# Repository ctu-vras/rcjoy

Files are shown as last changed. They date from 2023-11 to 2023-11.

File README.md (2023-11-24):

# rcjoy
Boost gamepad control of ROS robots to kilometer ranges and 100% reliability. Throw away all your nano dongles :)

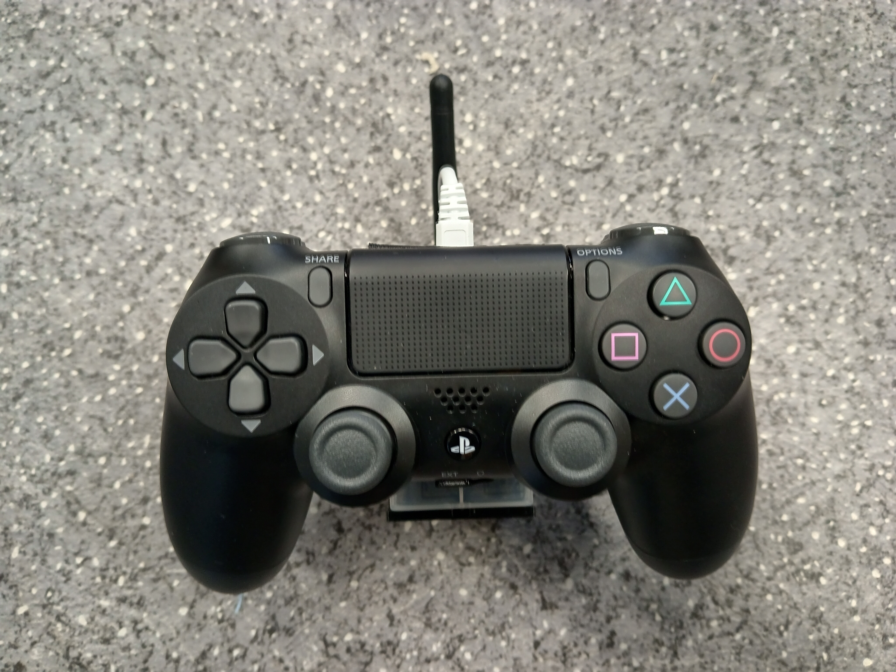
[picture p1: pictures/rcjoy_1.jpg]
rcjoy

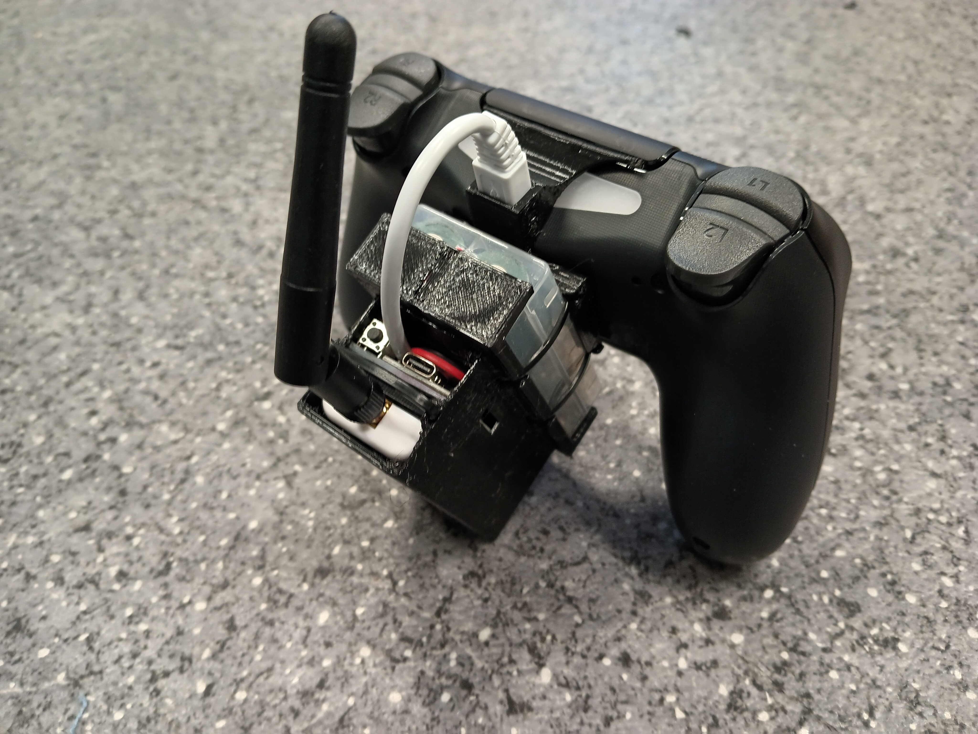
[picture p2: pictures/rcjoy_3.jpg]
rcjoy

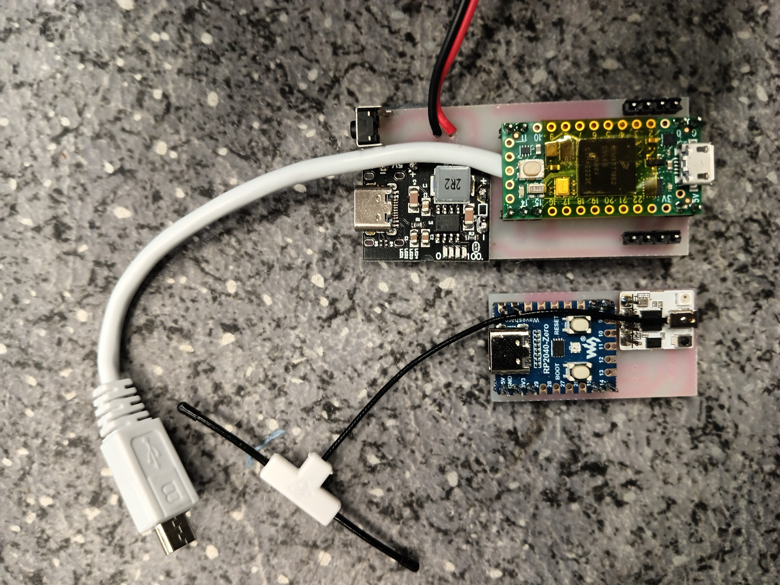
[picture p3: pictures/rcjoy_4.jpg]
rcjoy


# How it works
The rcjoy is intended to be a drop in replacement of a wireless gamepad like xbox controller or Logitech F710.  
The transmitter mcu (Teensy 4.0) acts as an usb host reading data from PS4 controller connected by wire, converts them to packets and send them via SBUS to tx module (ImmersionRC Ghost lite).  
The receiverer mcu (RP2040) acts as usb hid joystick emulator, reads SBUS packets decodes them and mimic gamepad controller connected to robot's PC.  
At this moment is communication one directional.

# BoM
  * PS4 Dualshock 4 controller  
   https://www.playstation.com/cs-cz/accessories/dualshock-4-wireless-controller/
  * ImmersionRC Ghost xLite Module  
   https://shop.orqafpv.com/products/immersionrc-immersionrc-ghost-xlite-module
  * ImmersionRC Ghost Atto Receiver  
   https://shop.orqafpv.com/products/immersionrc-immersionrc-ghost-atto-receiver
  * Teensy® 4.0 Development Board  
   https://www.pjrc.com/store/teensy40.html
  * Waveshare RP2040-Zero  
   https://www.waveshare.com/rp2040-zero.htm
  * Powerbank module  
   https://www.laskakit.cz/nabijecka-boost-pro-usb-powerbank-5v--usb-c/
  * Two LiIon 18650 cells

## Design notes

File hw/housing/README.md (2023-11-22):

# 3D printable mounting
The mounting hardware consists of universal DualShock 4 mount and main box with batteries. They attach togather with zip-ties running around the battery.
The 3D printing guide is available at https://www.printables.com/cs/model/655724-dualshock-4-range-extender-with-mount
The box is designed that it can be used as a stand for the controller itself. 

Reciever box is also provided which provides mounting for the antenna and the reciver itself. 

The wall mount is not required but provides a way of easily mounting the holder to a wall.

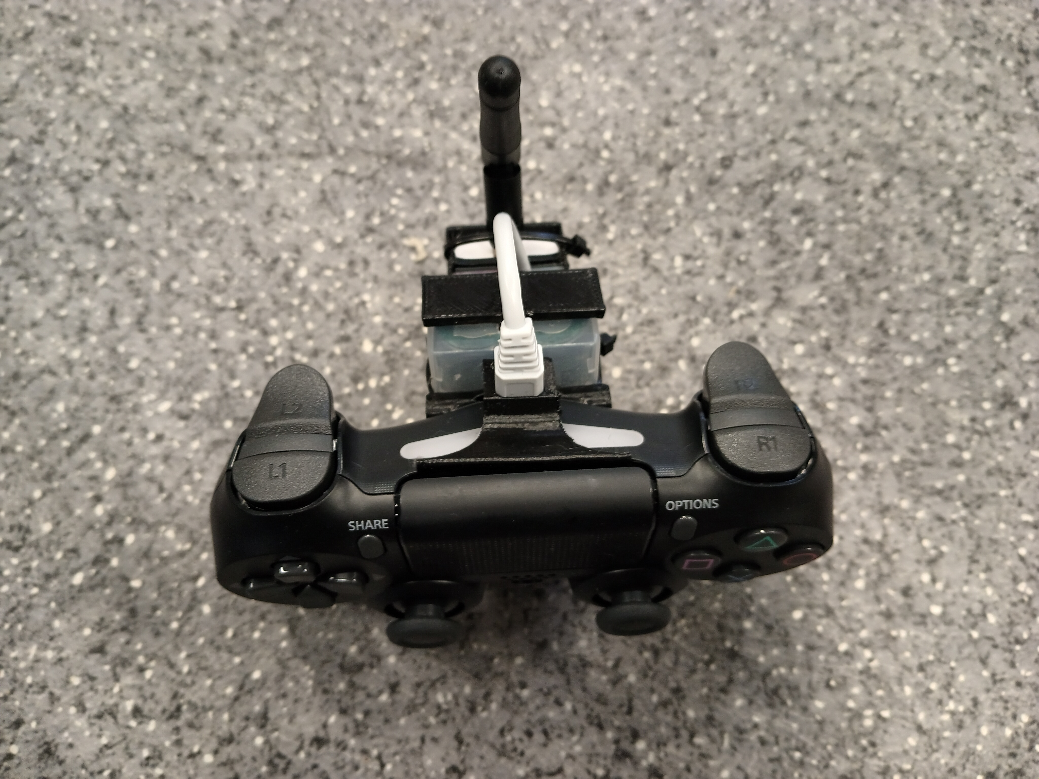
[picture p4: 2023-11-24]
pictures/rcjoy_2.jpg

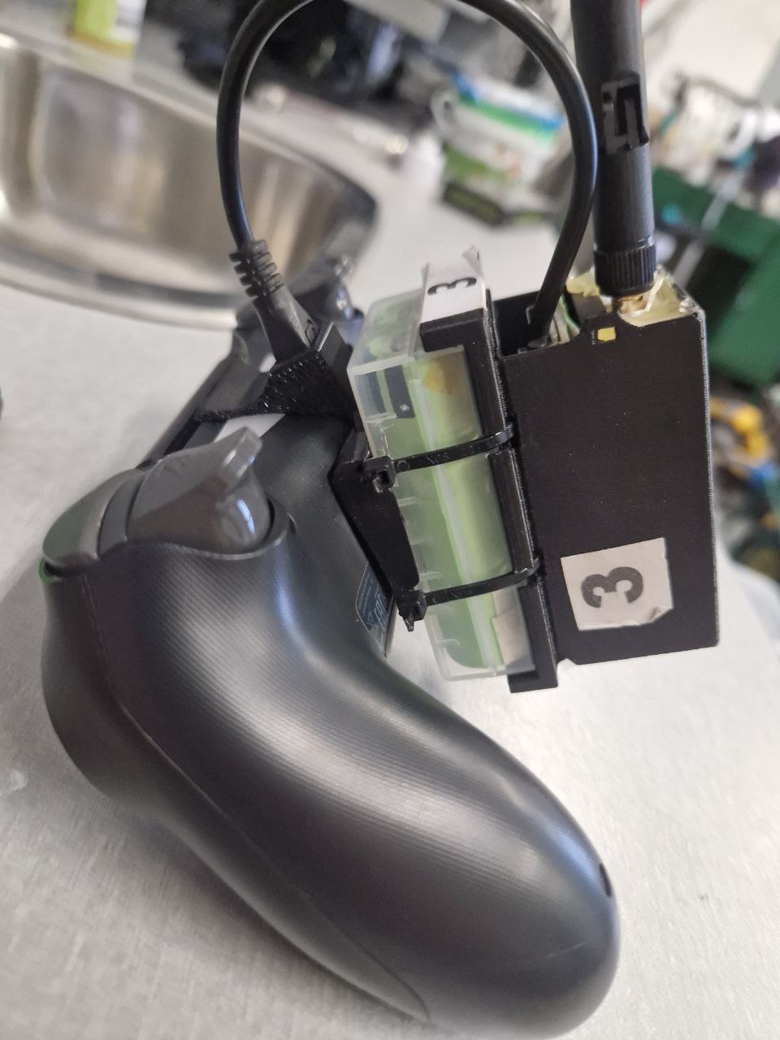
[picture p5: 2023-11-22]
hw/housing/final_assmbly.jpg

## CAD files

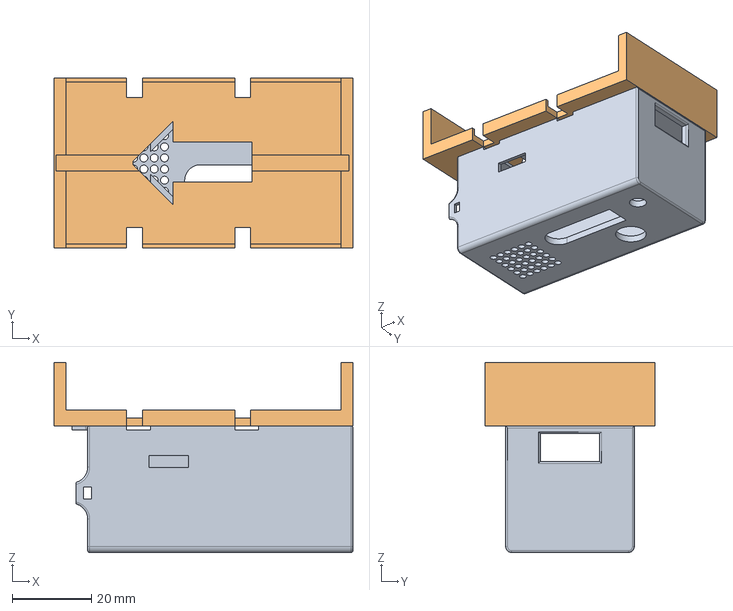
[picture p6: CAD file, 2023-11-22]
hw/housing/main_box_with_batteries.step
75.5 x 43.0 x 48.0 mm

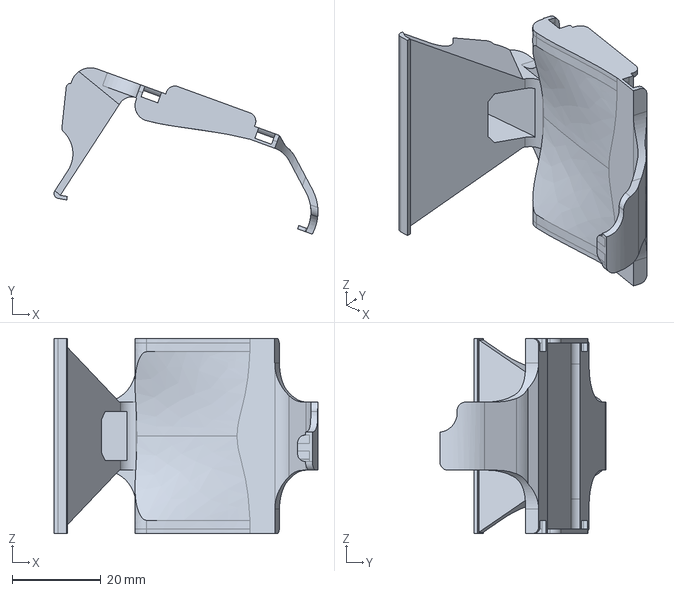
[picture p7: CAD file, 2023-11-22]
hw/housing/dualshock_4_mount.step
59.5 x 37.5 x 44.0 mm

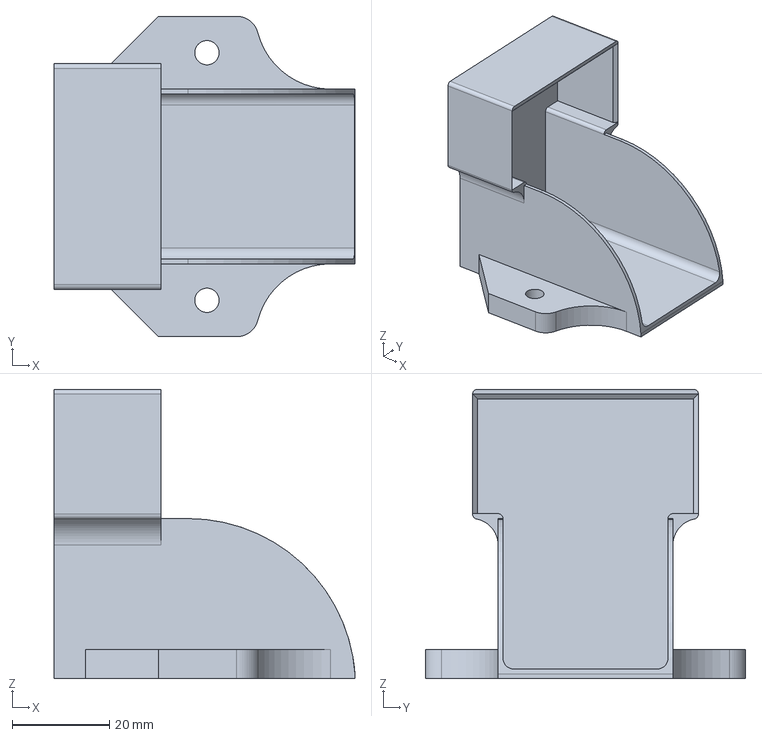
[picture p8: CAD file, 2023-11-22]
hw/housing/wall_mount.step
62.0 x 66.0 x 59.6 mm

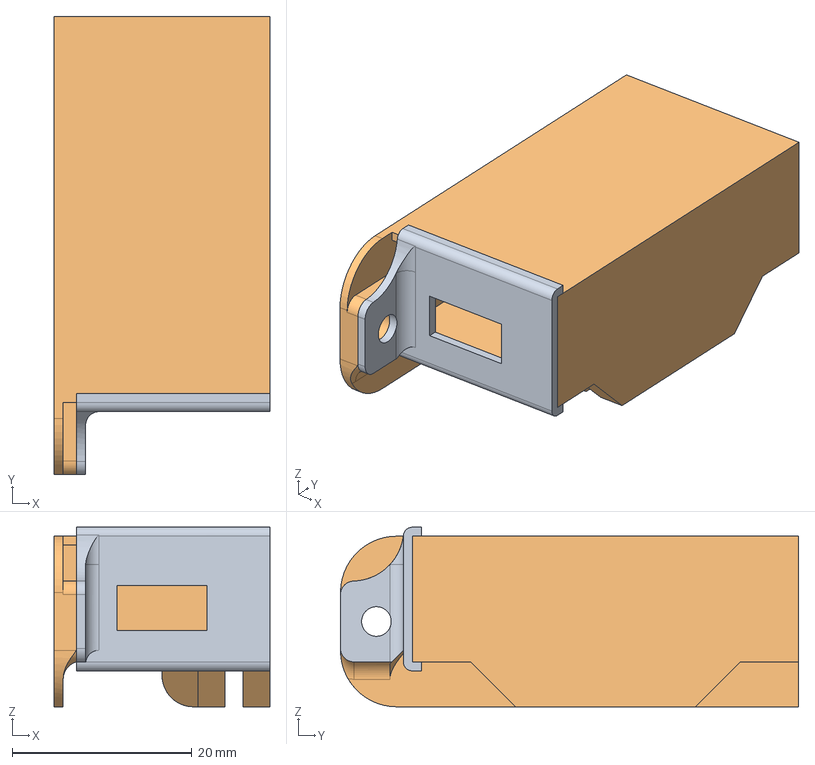
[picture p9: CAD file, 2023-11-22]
hw/housing/reciever_box.step
24.0 x 51.0 x 20.0 mm

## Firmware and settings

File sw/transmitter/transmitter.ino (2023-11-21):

//Teensy 4.0 code
//https://www.pjrc.com/store/teensy40.html


/*
  Exclusions for channels 0-3
  15
  271
  527
  783
  1039
  1295
  1551
  1807
  Channels 4-11 are just 8bit values, multiplication to full scale should work
  For simplicity all channels are considered as 8bit   
*/



#include "USBHost_t36.h"
//https://github.com/PaulStoffregen/USBHost_t36
//part of TeensyDuino 1.58
#include "sbus.h"
//https://github.com/bolderflight/sbus 
//v 8.1.4

uint8_t databyte[12];  //12 8-bit channels
bfs::SbusTx sbus_tx(&Serial3);
/* Array for storing SBUS data */
//std::array<int16_t, bfs::SbusRx::NUM_CH()> sbus_data;
bfs::SbusData sbus_data;


USBHost myusb;
USBHub hub1(myusb);
USBHIDParser hid1(myusb);

#define COUNT_JOYSTICKS 4
JoystickController joysticks[COUNT_JOYSTICKS] = {
  JoystickController(myusb), JoystickController(myusb),
  JoystickController(myusb), JoystickController(myusb)
};
int user_axis[64];
uint32_t buttons_prev = 0;

USBDriver *drivers[] = { &hub1, &joysticks[0], &joysticks[1], &joysticks[2], &joysticks[3], &hid1 };
#define CNT_DEVICES (sizeof(drivers) / sizeof(drivers[0]))
const char *driver_names[CNT_DEVICES] = { "Hub1", "joystick[0D]", "joystick[1D]", "joystick[2D]", "joystick[3D]", "HID1" };
bool driver_active[CNT_DEVICES] = { false, false, false, false };

// Lets also look at HID Input devices
USBHIDInput *hiddrivers[] = { &joysticks[0], &joysticks[1], &joysticks[2], &joysticks[3] };
#define CNT_HIDDEVICES (sizeof(hiddrivers) / sizeof(hiddrivers[0]))
const char *hid_driver_names[CNT_DEVICES] = { "joystick[0H]", "joystick[1H]", "joystick[2H]", "joystick[3H]" };
bool hid_driver_active[CNT_DEVICES] = { false };
bool show_changed_only = false;

uint8_t joystick_left_trigger_value[COUNT_JOYSTICKS] = { 0 };
uint8_t joystick_right_trigger_value[COUNT_JOYSTICKS] = { 0 };
uint64_t joystick_full_notify_mask = (uint64_t)-1;

int psAxis[64];
//int minaxis, maxaxis, mintrig, maxtrig;

uint8_t button[6];
uint16_t buttmp;



//=============================================================================
// Setup
//=============================================================================
void setup() {
  /* Begin the SBUS communication */
  databyte[0] = 127;
  databyte[1] = 127;
  databyte[2] = 0;
  databyte[3] = 127;
  databyte[4] = 127;
  databyte[5] = 0;
  databyte[6] = 0;
  databyte[7] = 0;
  databyte[8] = 4; //sbus data are generated by transmitter program
  databyte[9] = 0;
  databyte[10] = 0;
  databyte[11] = 0;
  for (uint8_t i = 0; i < 12; i++) {
    sbus_data.ch[i] = databyte[i] * 8;
  }
  
  sbus_tx.Begin();
  sbus_tx.data(sbus_data);
  sbus_tx.Write();

  Serial.begin(115200);

  Serial.println("PS4 GHOST RCJOY STARTING");
  myusb.begin();
}


//=============================================================================
// loop
//=============================================================================
void loop() {
  myusb.Task();



  //  for (int joystick_index = 0; joystick_index < COUNT_JOYSTICKS; joystick_index++)
  //    joysticks[joystick_index].axisChangeNotifyMask(joystick_full_notify_mask);

  for (int joystick_index = 0; joystick_index < COUNT_JOYSTICKS; joystick_index++)
    joysticks[joystick_index].axisChangeNotifyMask(0xffffffffffffffff);

  for (int joystick_index = 0; joystick_index < COUNT_JOYSTICKS; joystick_index++) {
    if (joysticks[joystick_index].available()) {
      //uint64_t axis_mask = joysticks[joystick_index].axisMask();
      //uint64_t axis_changed_mask = joysticks[joystick_index].axisChangedMask();
      uint32_t buttons = joysticks[joystick_index].getButtons();
      //Serial.printf("Joystick(%d): buttons = %x", joystick_index, buttons);
      //for (uint8_t i = 0; axis_mask != 0; i++, axis_mask >>= 1) {
      //  if (axis_mask & 1) {
      //    Serial.printf(" %d:%d", i, joysticks[joystick_index].getAxis(i));
      //    Serial.println();
      //  }
      //}
      switch (joysticks[joystick_index].joystickType()) {
        default:
          break;
        case JoystickController::PS4:
          {
            databyte[0] = joysticks[joystick_index].getAxis(0);
            databyte[1] = joysticks[joystick_index].getAxis(1);
            databyte[2] = joysticks[joystick_index].getAxis(3);
            databyte[3] = joysticks[joystick_index].getAxis(2);
            databyte[4] = joysticks[joystick_index].getAxis(5);
            databyte[5] = joysticks[joystick_index].getAxis(4);

            databyte[6] = 1 * (buttons & 0x0002) / 0x0002 +   //A CROSS
                          2 * (buttons & 0x0004) / 0x0004 +   //B CIRCLE
                          4 * (buttons & 0x0001) / 0x0001 +   //X SQUARE
                          8 * (buttons & 0x0008) / 0x0008 +   //Y TRIANGLE
                          16 * (buttons & 0x0010) / 0x0010 +  //LTRIG
                          32 * (buttons & 0x0020) / 0x0020 +  //RTRIG
                          64 * (buttons & 0x0100) / 0x0100 +  //SHARE
                          128 * (buttons & 0x0200) / 0x0200;  //RHAT
                                                              //64 * (buttons & 0x0400) / 0x0400 + //LHAT
                                                              //128 * (buttons & 0x0800) / 0x0800; //RHAT
            //databyte[7] = 0;
            databyte[7] = 0 + 1 * (buttons & 0x1000) / 0x1000 +  //PS
                          2 * (buttons & 0x0400) / 0x0400 +      //LHAT
                          4 * (buttons & 0x0800) / 0x0800 +      //RHAT
                          8 * (buttons & 0x2000) / 0x2000;       //TOUCH

            //databyte[8] = ((joysticks[joystick_index].getAxis(9) & 0b00000111) + 1);
            uint8_t hat = joysticks[joystick_index].getAxis(9);
            //(hat == 8) ? databyte[8] = 0 : (databyte[8] = hat + 1) * 16;
            if (hat != 8) databyte[7] += (hat + 1) * 16;
            /*databyte[8] = 0;
            switch (joysticks[joystick_index].getAxis(9)) {
              case 0: databyte[8] += 1; break;
              case 1: databyte[8] += 2; break;
              case 2: databyte[8] += 3; break;
              case 3: databyte[8] += 4; break;
              case 4: databyte[8] += 5; break;
              case 5: databyte[8] += 6; break;
              case 6: databyte[8] += 7; break;
              case 7: databyte[8] += 8; break;
              case 8: databyte[8] += 0; break;
              default: break;
            }
            */
            //databyte[8]=4;


            for (uint8_t n = 0; n < 12; n++) {
              Serial.println(databyte[n]);
            }
            Serial.println();
            //Serial.println(millis());
          }
          for (uint8_t i = 0; i < 12; i++) {
            sbus_data.ch[i] = databyte[i] * 8;
          }
          sbus_data.ch[8]=32; //sbus data are generated by transmitter program
          sbus_tx.data(sbus_data);
          sbus_tx.Write();

          Serial.println();
          joysticks[joystick_index].joystickDataClear();
      }
    }
  }
  PrintDeviceListChanges();
  delay(20);
}

//=============================================================================
// Show when devices are added or removed
//=============================================================================
void PrintDeviceListChanges() {
  for (uint8_t i = 0; i < CNT_DEVICES; i++) {
    if (*drivers[i] != driver_active[i]) {
      databyte[0] = 127;
      databyte[1] = 127;
      databyte[2] = 0;
      databyte[3] = 127;
      databyte[4] = 127;
      databyte[5] = 0;
      databyte[6] = 0;
      databyte[7] = 0;
      databyte[8] = 4; //sbus data are generated by transmitter program
      databyte[9] = 0;
      databyte[10] = 0;
      databyte[11] = 0;
      for (uint8_t i = 0; i < 12; i++) {
        sbus_data.ch[i] = databyte[i] * 8;
      }
      sbus_tx.data(sbus_data);
      sbus_tx.Write();

      if (driver_active[i]) {
        Serial.printf("*** Device %s - disconnected ***\n", driver_names[i]);
        driver_active[i] = false;

      } else {
        Serial.printf("*** Device %s %x:%x - connected ***\n", driver_names[i], drivers[i]->idVendor(), drivers[i]->idProduct());
        driver_active[i] = true;

        const uint8_t *psz = drivers[i]->manufacturer();
        if (psz && *psz) Serial.printf("  manufacturer: %s\n", psz);
        psz = drivers[i]->product();
        if (psz && *psz) Serial.printf("  product: %s\n", psz);
        psz = drivers[i]->serialNumber();
        if (psz && *psz) Serial.printf("  Serial: %s\n", psz);
      }
    }
  }

  for (uint8_t i = 0; i < CNT_HIDDEVICES; i++) {
    if (*hiddrivers[i] != hid_driver_active[i]) {
      databyte[0] = 127;
      databyte[1] = 127;
      databyte[2] = 0;
      databyte[3] = 127;
      databyte[4] = 127;
      databyte[5] = 0;
      databyte[6] = 0;
      databyte[7] = 0;
      databyte[8] = 4; //sbus data are generated by transmitter program
      databyte[9] = 0;
      databyte[10] = 0;
      databyte[11] = 0;
      for (uint8_t i = 0; i < 12; i++) {
        sbus_data.ch[i] = databyte[i] * 8;
      }
      sbus_tx.data(sbus_data);
      sbus_tx.Write();

      if (hid_driver_active[i]) {
        Serial.printf("*** HID Device %s - disconnected ***\n", hid_driver_names[i]);
        hid_driver_active[i] = false;

      } else {
        Serial.printf("*** HID Device %s %x:%x - connected ***\n", hid_driver_names[i], hiddrivers[i]->idVendor(), hiddrivers[i]->idProduct());
        hid_driver_active[i] = true;

        const uint8_t *psz = hiddrivers[i]->manufacturer();
        if (psz && *psz) Serial.printf("  manufacturer: %s\n", psz);
        psz = hiddrivers[i]->product();
        if (psz && *psz) Serial.printf("  product: %s\n", psz);
        psz = hiddrivers[i]->serialNumber();
        if (psz && *psz) Serial.printf("  Serial: %s\n", psz);
      }
    }
  }
}

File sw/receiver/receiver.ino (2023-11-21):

//RPi pico code 
//Waveshare RP2040 zero
//https://www.waveshare.com/wiki/RP2040-Zero

#include <Adafruit_TinyUSB.h>
//Change USB Stack to "Adafruit TinyUSB"

#include "sbus.h"
//https://github.com/bolderflight/sbus 
//v 8.1.4
#include <Adafruit_NeoPixel.h>
//https://github.com/adafruit/Adafruit_NeoPixel
//V1.12.0

extern "C" {
#include <hardware/watchdog.h>
};
//https://raspberrypi.github.io/pico-sdk-doxygen/group__hardware__watchdog.html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

// HID report descriptor using TinyUSB's template
// Single Report (no ID) descriptor
uint8_t const desc_hid_report[] = {
  TUD_HID_REPORT_DESC_GAMEPAD()
};

// USB HID object. For ESP32 these values cannot be changed after this declaration
// desc report, desc len, protocol, interval, use out endpoint
Adafruit_USBD_HID usb_hid(desc_hid_report, sizeof(desc_hid_report), HID_ITF_PROTOCOL_NONE, 2, false);

// Report payload defined in src/class/hid/hid.h
// - For Gamepad Button Bit Mask see  hid_gamepad_button_bm_t
// - For Gamepad Hat    Bit Mask see  hid_gamepad_hat_t
hid_gamepad_report_t gp;






/* SbusRx object on Serial1 */
bfs::SbusRx sbus_rx(&Serial1);
//std::array<int16_t, bfs::SbusRx::NUM_CH()> sbus_data;
bfs::SbusData sbus_data;

uint16_t buttmp1, buttmp2;
uint32_t buttmp;
uint8_t button1[8], button2[8];

Adafruit_NeoPixel pixels(1, 16, NEO_RGB + NEO_KHZ800);
uint8_t r, g, b;

uint64_t lastRXtime;
uint32_t timeout = 1000;
uint32_t timeout_count = 10;

void setup() {
  TinyUSBDevice.setSerialDescriptor("rcjoy");
  Serial.begin(115200);
  // Serial to display the received data

#if defined(ARDUINO_ARCH_MBED) && defined(ARDUINO_ARCH_RP2040)
  // Manual begin() is required on core without built-in support for TinyUSB such as mbed rp2040
  TinyUSB_Device_Init(0);
#endif


  usb_hid.begin();

  // wait until device mounted
  while (!TinyUSBDevice.mounted()) delay(1);

  gp.x = 0;
  gp.y = 0;
  gp.z = -127;
  gp.rx = 0;
  gp.ry = 0;
  gp.rz = -127;
  gp.hat = 0;
  gp.buttons = 0;  //Maybe DMS should be forced to push???
  usb_hid.sendReport(0, &gp, sizeof(gp));

  //Serial.begin(115200);
  //while (!Serial) {}

  /* Begin the SBUS communication */
  sbus_rx.Begin();


  Serial.println("rcjoy Init");
  //pinMode(25, OUTPUT);

  pixels.begin();
  pixels.clear();
  pixels.setPixelColor(0, pixels.Color(0, 0, 0));
  pixels.show();
  watchdog_enable(100000, 1);
}

void loop() {

  if (lastRXtime + timeout < millis()) {
    Serial.println("Timeout!");
    r = 255;
    g = 0;
    gp.x = 0;
    gp.y = 0;
    gp.z = -127;
    gp.rx = 0;
    gp.ry = 0;
    gp.rz = -127;
    gp.hat = 0;
    gp.buttons = 0;  //Maybe DMS should be forced to push???
    usb_hid.sendReport(0, &gp, sizeof(gp));
    delay(100);
  } else {
    watchdog_update();
    r = 0;
    g = 255;
  }

  if (!usb_hid.ready()) {
    //return;
    b = 255;
  } else {
    b = 0;
  }
  pixels.setPixelColor(0, pixels.Color(r, g, b));
  pixels.show();

  //if ((sbus_rx.Read()) && (sbus_data.ch[8]==32)) {
  if (sbus_rx.Read()) {
    lastRXtime = millis();
    sbus_data = sbus_rx.data();
    /* Display the received data */

    for (int i = 0; i < 9; i++) {
      Serial.print(sbus_data.ch[i] / 8);
      Serial.print(",");
    }
    Serial.println();

    buttmp1 = sbus_data.ch[6] / 8;
    for (uint8_t b = 0; b < 8; b++) {
      button1[b] = buttmp1 % 2;
      buttmp1 /= 2;
      Serial.print(button1[b]);
      Serial.print("\t");
    }

    buttmp2 = ((sbus_data.ch[7] / 8) & 0b1111);
    for (uint8_t b = 0; b < 8; b++) {
      button2[b] = buttmp2 % 2;
      buttmp2 /= 2;
      Serial.print(button2[b]);
      Serial.print("\t");
    }

    Serial.println("");
    //Serial.println("");


    buttmp = 1 * button1[0] + 2 * button1[1] + 4 * button1[2] + 8 * button1[3] + 16 * button1[4] + 32 * button1[5] + 64 * button1[6] + 128 * button1[7] + 256 * button2[0] + 512 * button2[1] + 1024 * button2[2] + 2048 * button2[3] + 4096 * button2[4] + 8192 * button2[5] + 16384 * button2[6] + 32768 * button2[7];

    //if (!sbus_data.failsafe) {
    //digitalWrite(25, HIGH);
    if (sbus_data.ch[8]==32) { //Sbus data are generated by transmitter program 
    gp.x = map(sbus_data.ch[0] / 8, 0, 255, -127, 127);
    gp.y = map(sbus_data.ch[1] / 8, 0, 255, -127, 127);
    gp.z = map(sbus_data.ch[2] / 8, 0, 255, -127, 127);
    gp.rx = map(sbus_data.ch[3] / 8, 0, 255, -127, 127);
    gp.ry = map(sbus_data.ch[4] / 8, 0, 255, -127, 127);
    gp.rz = map(sbus_data.ch[5] / 8, 0, 255, -127, 127);
    gp.hat = sbus_data.ch[7] / 128;  //8*16!!!!
    gp.buttons = buttmp;
    }
    /* } else {
      //digitalWrite(25, LOW);
      gp.x = 0;
      gp.y = 0;
      gp.z = -127;
      gp.rx = 0;
      gp.ry = 0;
      gp.rz = -127;
      gp.hat = 0;
      gp.buttons = 0;  //DMS ???
    }
    Serial.print("FAILSAFE: ");
    Serial.println(sbus_data.failsafe);
    Serial.print("LOST FRAME: ");
    Serial.println(sbus_data.lost_frame);
    */
    usb_hid.sendReport(0, &gp, sizeof(gp));
  }
}

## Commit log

2023-11-21 Add hw + sw
    [ghost_lite_tx.kicad_pcb, ghost_lite_tx.kicad_sch, ghost_lite_tx_conn.kicad_pcb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]
2023-11-22 3D models added
    [dualshock_4_mount.step, main_box_with_batteries.step, reciever_box.step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]
2023-11-22 pictures of assembly
